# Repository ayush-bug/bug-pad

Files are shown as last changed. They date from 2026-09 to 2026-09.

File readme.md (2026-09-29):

# BUGPAD
 This is my first hardware project  bugpad.
 
A 4 keys micropad to play hillclimb racing with and a rotatory encoder and a oled , 

built for hackclub hackpad mission.

bug-pad 

 
# About
This is a  micropad , with 4 switches , 1 encoder and a oled display . 

the switches work as a arrow key , encoder is for volume , and oled show which key is pressed . 

So you can play hillclimb racing and chrome dino with this bug pad .

# Features 
 - four mechanical switches
 - a encoder for volume
 - a oled display
 - and a insane 3d case

# CAD MODEL
 first of all thanks to  <a href="https://stardance.hackclub.com/@Jacube1234">@Jacube1234</a> that help me a lot to learn cad in fusion 360 .

 All cad design is made in fusion 360 

 cad model

 the case is divided into 3 parts  bottom , top and  plate .

 # PCB
  THE pcd is designed in kicad , also this is my first pcb design , 

  it is quiet is then i thought . 

  i just started and sow some tutorials on yt and done this .
  
Schematic

pcb
    
Layout

layout

Final PCB

PCB

pcb-back

# FIRMWARE

my bugpad usage qmk firmware

# BILL OF MATERIAL (BOM)

  - 1  Unsoldered Seeed XIAO RP2040
  - 4x MX-Style switches
  - 1x EC11E Rotary Encoder
  - 4x M3x16mm screws
  - 1x 0.91 inch OLED display
  - custom pcb
  - custom 3d case

# thanks note
 thanks <a href="https://stardance.hackclub.com/@Jacube1234">@Jacube1234</a> and <a href="https://stardance.hackclub.com/@Nemo_Donut">nemo </a>for you help it mean a lot , thanks a lot.

<pre>
  Made with love by Ayush 
</pre>

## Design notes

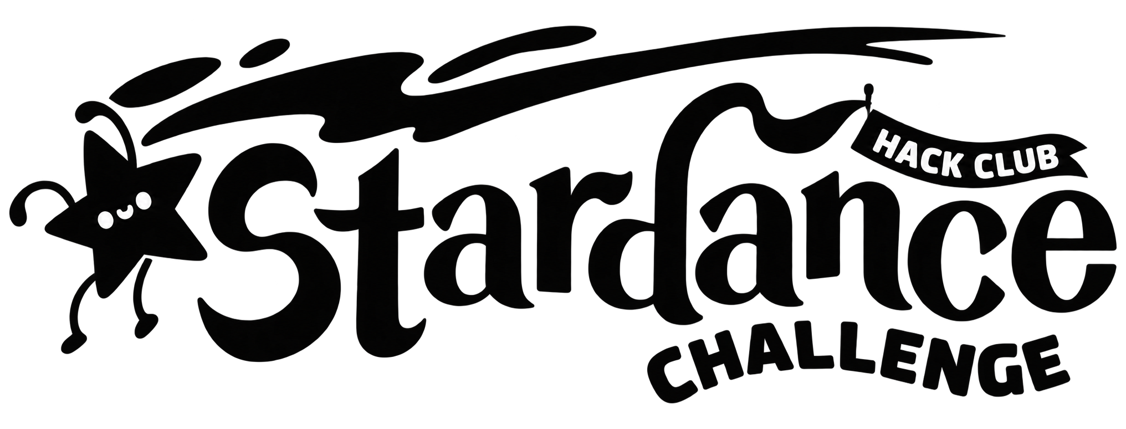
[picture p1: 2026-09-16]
assets/ChatGPT Image Sep 16, 2026, 11_28_27 PM.png

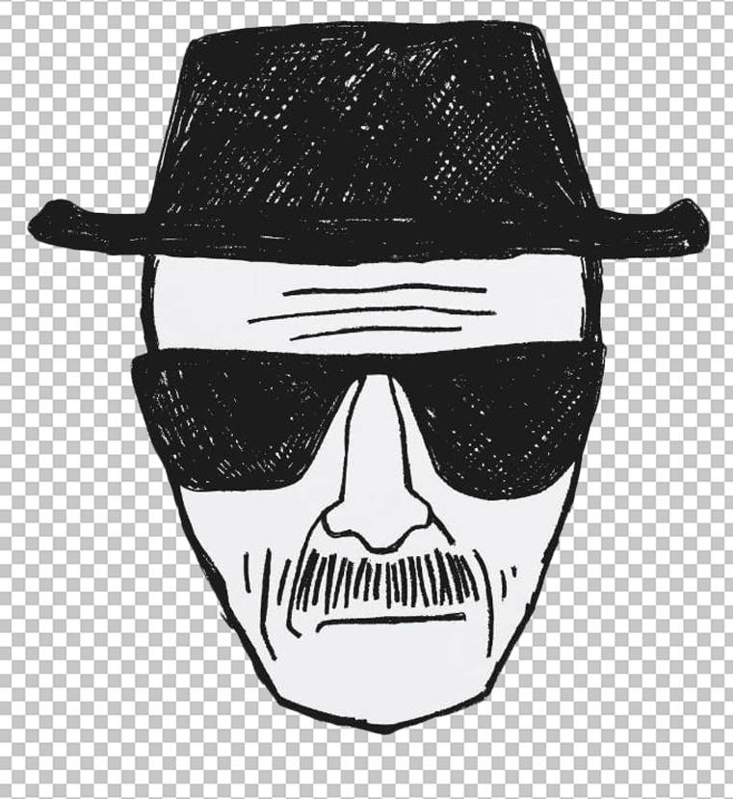
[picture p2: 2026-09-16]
assets/hisenberg.jpg

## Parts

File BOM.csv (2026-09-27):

S.No. | Quantity Required | Item Description
1 | 1 | Custom PCB
2 | 1 | 3d Printed Case
3 | 4 | SW_Push
4 | 1 | RotaryEncoder_Switch
5 | 1 | MODULE-SEEEDUINO-XIAO
6 | 1 | ER-OLED0.91-1-I2C
7 | 4 | M3x16mm

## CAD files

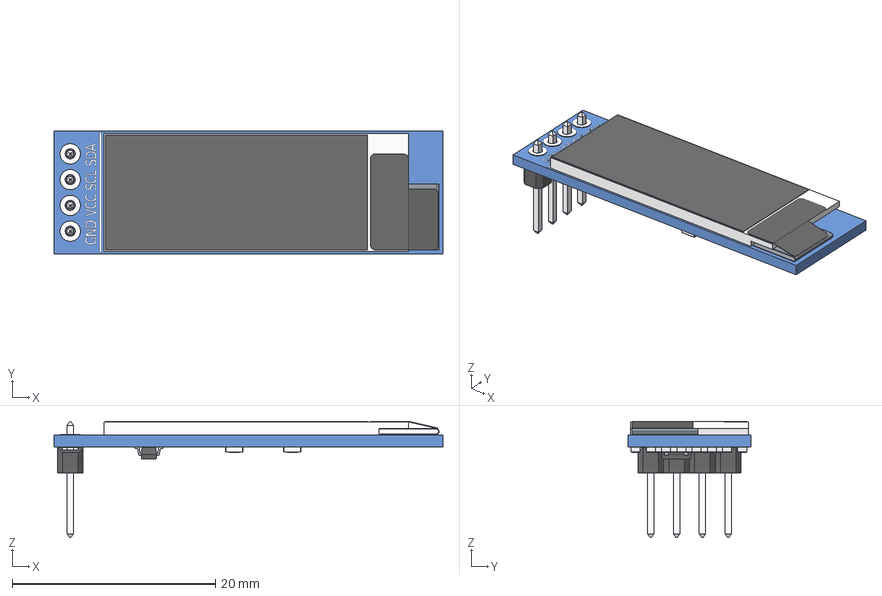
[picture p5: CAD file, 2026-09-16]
3d-components-cad/OLED_0.91_128x32.stp
38.3 x 12.1 x 11.5 mm
OLED_0.91_128x32
Pin Header 4 x 1 TH 2.54mm Pitch
RESC-0603 x 13
2SD0601A

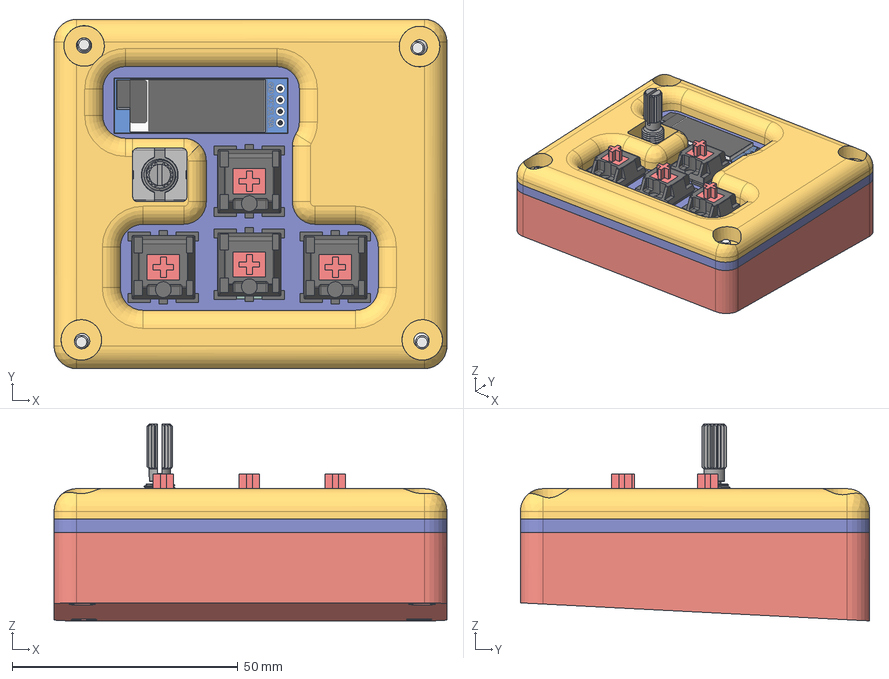
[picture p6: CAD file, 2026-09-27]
CAD/bug-pad.step
87.1 x 77.4 x 43.6 mm
VITE_TESTA_SVASATA_PHILLIPS x 4

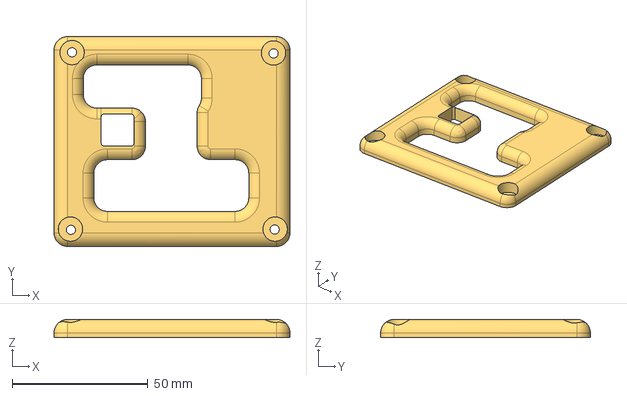
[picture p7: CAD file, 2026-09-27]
Producton/Shell.step
87.1 x 77.4 x 6.70 mm

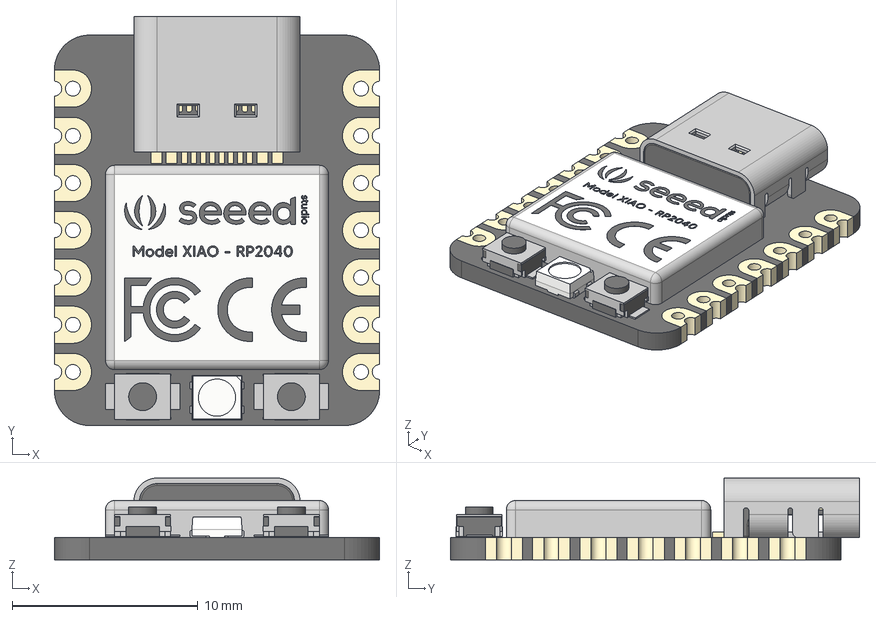
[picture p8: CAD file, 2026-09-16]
3d-components-cad/Seeed Studio XIAO RP2040 v26 (1).step
17.5 x 22.0 x 4.40 mm
type-c v2
smd_button v3
DOUT
DIN
VSS
VDD
smd_button v3(Mirror)

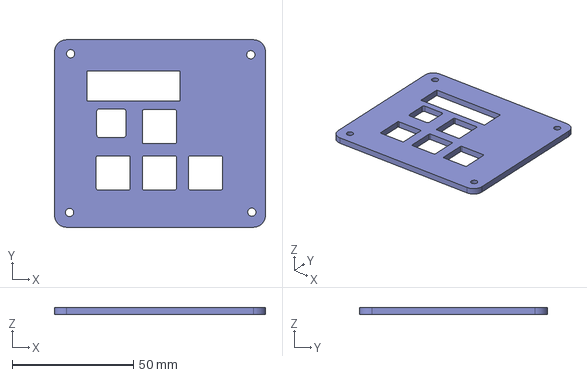
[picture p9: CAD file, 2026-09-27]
Producton/Plate.step
87.1 x 77.4 x 3.00 mm

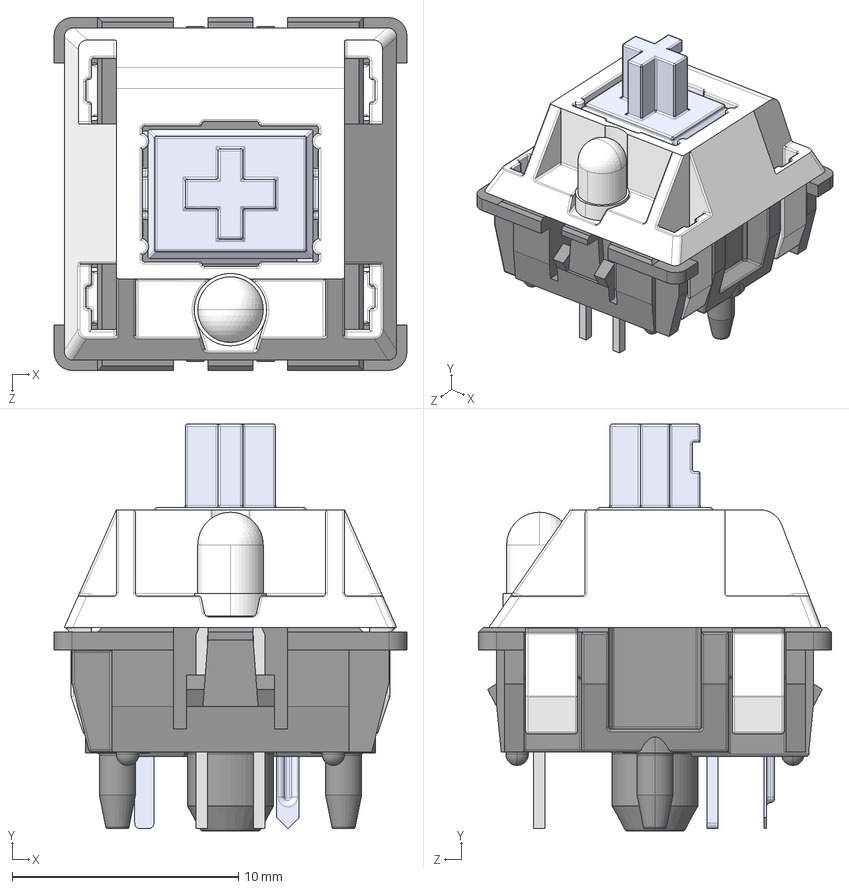
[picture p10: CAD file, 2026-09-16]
3d-components-cad/Cherry MX.STEP
15.6 x 18.0 x 15.6 mm
Bottom
Pulsador
Top
Pieza5^Cherry MX
Pin1
Pin2
Led 3mm_trans

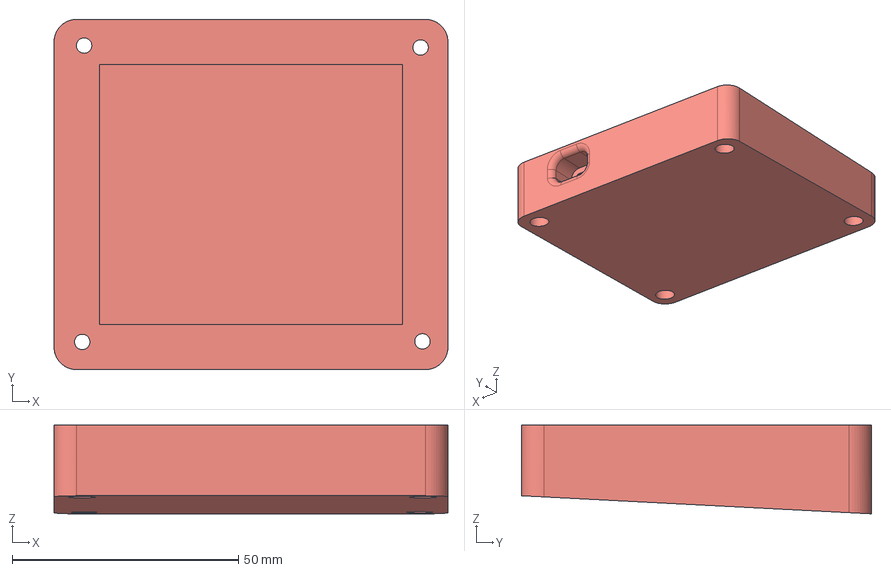
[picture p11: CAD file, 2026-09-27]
Producton/Base.step
87.1 x 77.4 x 19.6 mm

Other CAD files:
CAD/bug-pad.f3z

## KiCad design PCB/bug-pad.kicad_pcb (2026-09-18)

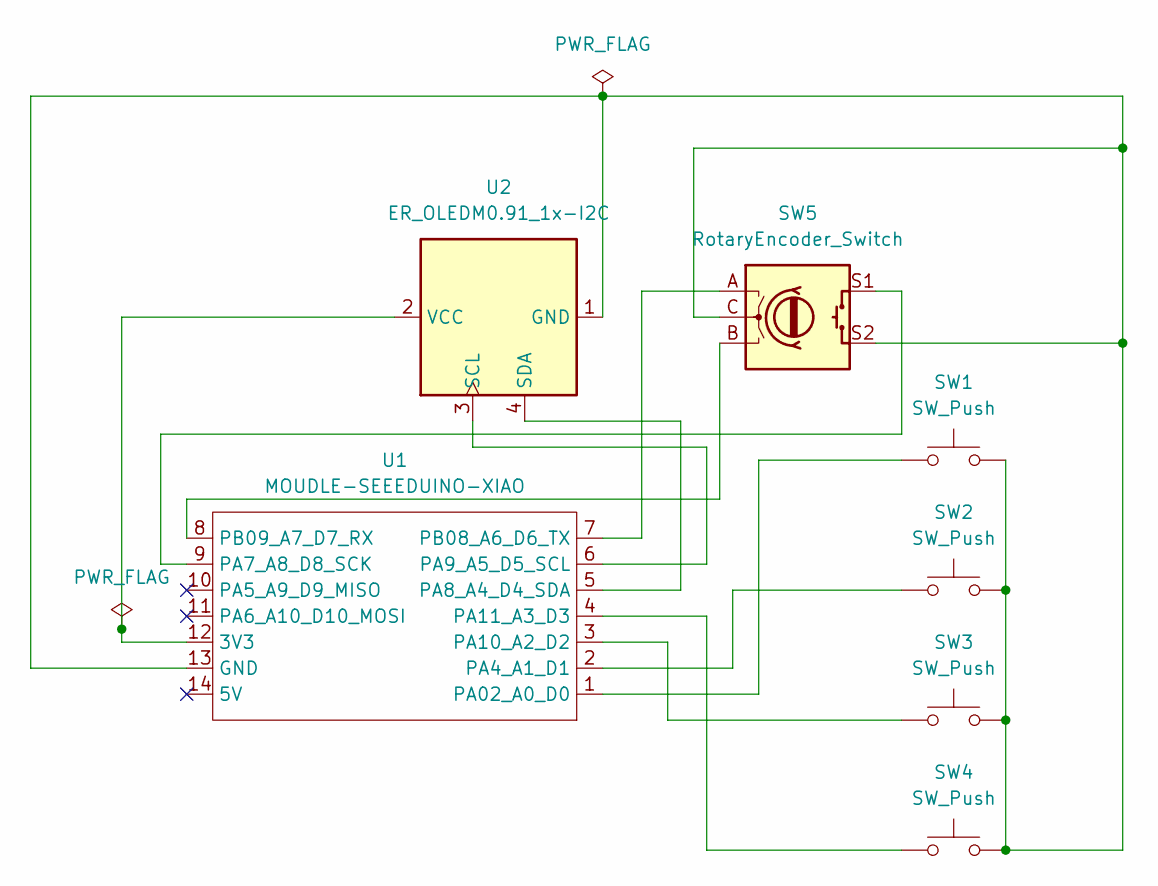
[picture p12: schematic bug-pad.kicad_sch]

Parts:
SW1, SW2, SW3, SW4: SW_Push; SW_Cherry_MX_1.00u_PCB
SW5: RotaryEncoder_Switch; RotaryEncoder_Alps_EC11E-Switch_Vertical_H20mm
U1: MOUDLE-SEEEDUINO-XIAO; XIAO-Generic-Hybrid-14P-2.54-21X17.8MM
U2: ER_OLEDM0.91_1x-I2C

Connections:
unnamed: U1.12 (3V3), U2.2 (VCC)
unnamed: SW1.2, SW2.2, SW3.2, SW4.2, SW5.C, SW5.S2, U1.13 (GND), U2.1 (GND)
unnamed: SW1.1, U1.1 (PA02_A0_D0)
unnamed: SW2.1, U1.2 (PA4_A1_D1)
unnamed: SW5.S1, U1.9 (PA7_A8_D8_SCK)
unnamed: U1.5 (PA8_A4_D4_SDA), U2.4 (SDA)
unnamed: U1.6 (PA9_A5_D5_SCL), U2.3 (SCL)
unnamed: SW3.1, U1.3 (PA10_A2_D2)
unnamed: SW4.1, U1.4 (PA11_A3_D3)
unnamed: SW5.A, U1.7 (PB08_A6_D6_TX)
unnamed: SW5.B, U1.8 (PB09_A7_D7_RX)

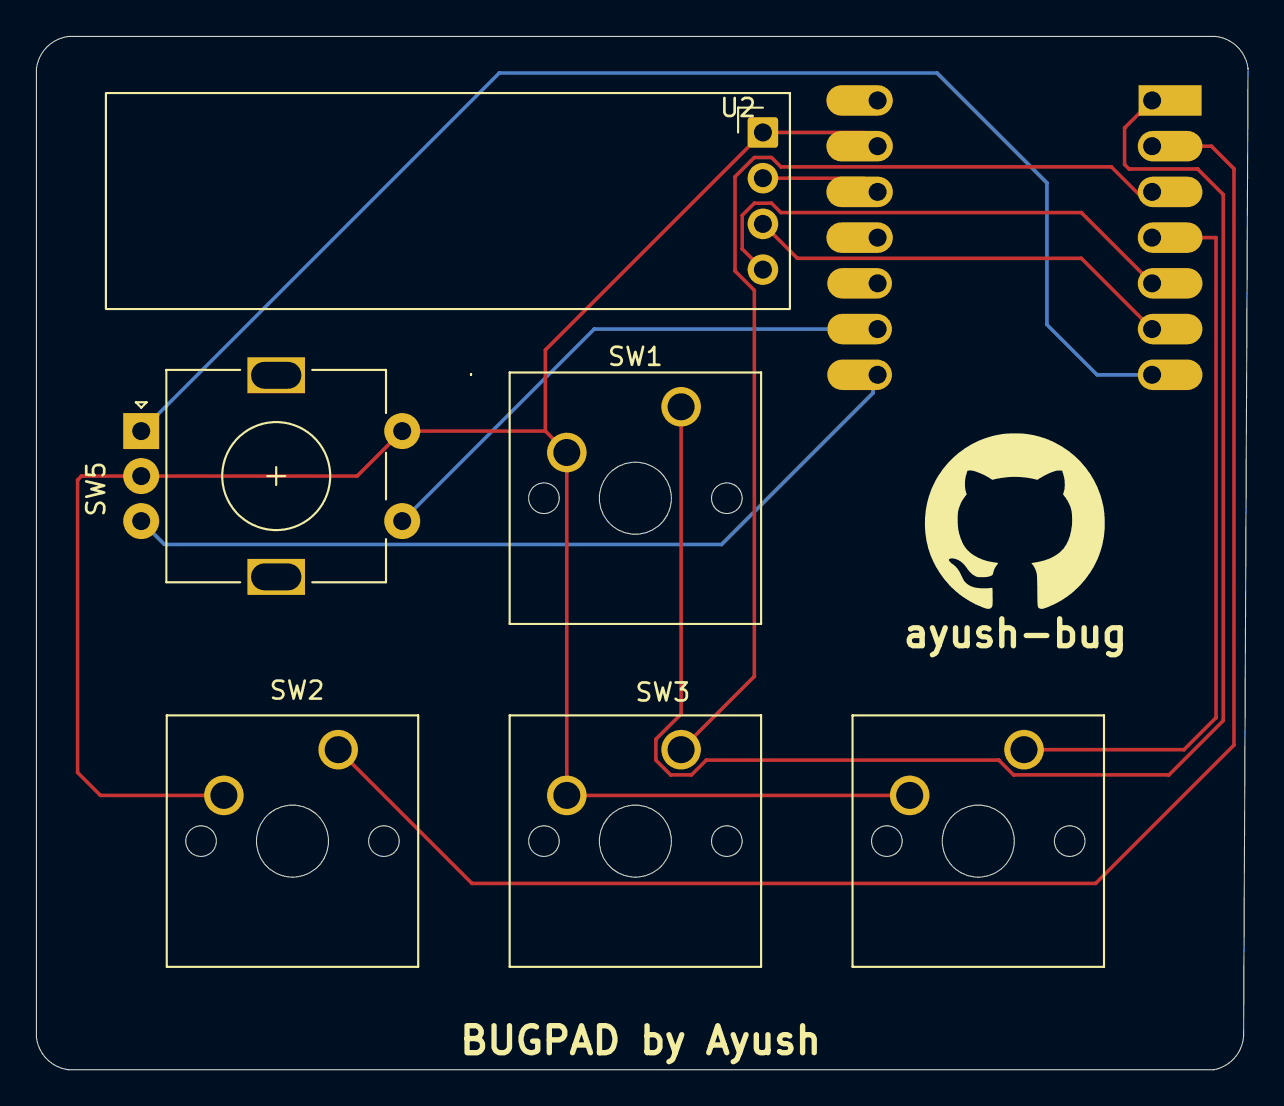
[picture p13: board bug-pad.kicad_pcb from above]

Board: 2 copper layers, 67.3 x 57.4 mm, 7 parts (1 on the bottom side), 11 nets.

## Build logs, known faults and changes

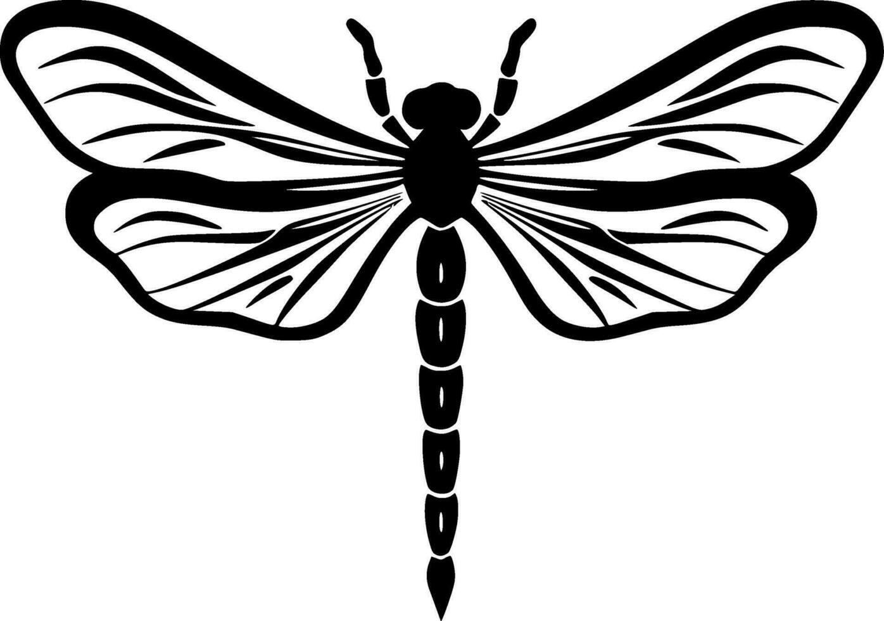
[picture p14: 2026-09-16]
assets/bug-butterfly.jpg

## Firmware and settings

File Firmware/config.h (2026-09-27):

#pragma once

#define I2C_DRIVER I2CD1
#define I2C1_SDA_PIN GP6
#define I2C1_SCL_PIN GP7

#define OLED_DISPLAY_128X32
#define OLED_DISPLAY_ADDRESS 0x3C
#define OLED_BRIGHTNESS 128

#define RP2040_BOOTLOADER_DOUBLE_TAP_RESET
#define RP2040_BOOTLOADER_DOUBLE_TAP_RESET_TIMEOUT 200U

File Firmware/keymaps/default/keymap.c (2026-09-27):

#include QMK_KEYBOARD_H


#define ENCODER_BUTTON_PIN GP2


const uint16_t PROGMEM keymaps[][MATRIX_ROWS][MATRIX_COLS] = {
    [0] = LAYOUT(
        KC_UP,
        KC_DOWN,
        KC_LEFT,
        KC_RIGHT
    )
};


bool encoder_update_user(uint8_t index, bool clockwise) {
    if (index == 0) {
        if (clockwise) {
            tap_code(KC_VOLU);
        } else {
            tap_code(KC_VOLD);
        }
    }

    return false;
}


void keyboard_post_init_user(void) {
    gpio_set_pin_input_high(ENCODER_BUTTON_PIN);
}

void matrix_scan_user(void) {
    static bool last_state = true;
    static uint32_t last_change = 0;

    bool current_state = gpio_read_pin(ENCODER_BUTTON_PIN);

    if (current_state != last_state &&
        timer_elapsed32(last_change) > 30) {

        last_state = current_state;
        last_change = timer_read32();

        // Active-low button: LOW = pressed
        if (!current_state) {
            tap_code(KC_MUTE);
        }
    }
}


#ifdef OLED_ENABLE

bool oled_task_user(void) {
    oled_write_ln_P(PSTR("BUGPAD"), false);
    oled_write_ln_P(PSTR("-----------"), false);
    oled_write_ln_P(PSTR("UP DOWN"), false);
    oled_write_ln_P(PSTR("LEFT RIGHT"), false);
    oled_write_ln_P(PSTR("ENC: VOL"), false);
    oled_write_ln_P(PSTR("PRESS: MUTE"), false);

    return false;
}

#endif

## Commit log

2026-09-15 gettingstarted with bug pad
    [bug-pad.kicad_pcb, bug-pad.kicad_sch]
2026-09-16 resolved some important warning and added images to pcb.
    [bug-pad.kicad_pcb, bug-pad.kicad_sch]
2026-09-16 added all the 3d components cad
    [Cherry MX.STEP, OLED_0.91_128x32.stp, Seeed Studio XIAO RP2040 v26 (1).step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]
2026-09-16 added interactive images on pcb
    [bug-pad.kicad_pcb]
2026-09-17 generated gerber file
    [bug-pad-B_Cu.gbr, bug-pad-B_Mask.gbr, bug-pad-B_Paste.gbr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]
2026-09-18 change the design and size of pcb
    [bug-pad.kicad_pcb, bug-pad.step]
2026-09-18 updated the gerber file
    [bug-pad-B_Cu.gbr, bug-pad-B_Mask.gbr, bug-pad-B_Paste.gbr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]
2026-09-21 updated cad
    [bug-pad-cad.f3z, bug-pad.step]
2026-09-21 added BOM for components
    [BOM.csv]
2026-09-22 organised folders
    [bug-pad-cad.f3z, bug-pad.f3z, bug-pad.kicad_pcb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]
2026-09-27 updated the BOM.csv
    [BOM.csv]
2026-09-27 updated model
    [Base.step, Plate.step, Shell.step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]
